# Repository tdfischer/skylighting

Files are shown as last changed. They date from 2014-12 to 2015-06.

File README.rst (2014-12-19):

Noisebridge's skylights are boring and dull.

Lets make them shiny shiny!

The Idea
========

In all of Noisebridge's skylights, a set of RGB LED strips at the base.
Each controlled by a standalone microprocessor connected via ZigBee,
with the network as a whole controlled by a RaspberryPI base station.

The system should be as `Anti-Fragile <Anti-Fragile>`__ as possible:

-  If the power goes out, it should come back on and look neat
-  Each skylight can act independently of hardware failure of any other
   skylight
-  Multiple base station designs can be used to control simultaneously,
   as long as can speak a protocol over ZigBee
-  Wireless by default, wired if available
-  Use of DNS-SD so you don't have to scan the network to find a damn
   basestation
-  Replacing parts is really cheap and easy to do
-  Solar powered, so as to not rely on The Grid
-  Some sort of "Sleep Mode" that is launched after a period of
   inactivity or missing heartbeat

Some really neat uses:

-  Clicking a spot on a map on `Infobanana <Infobanana>`__ turns the
   overhead lighting into a magical directional indicator
-  When someone buzzes the door, perhaps a certain pattern could be
   shown
-  A UI that lets one configure each cell's RGB for an event
-  Automatically turning on/off based on a motion sensor grid in the
   space

The Software
============

-  **`Skyglighting on
   Github <https://github.com/tdfischer/skylighting>`__ - Main issue
   tracker**
-  `Graviton <http://git.phrobo.net/cgit/graviton.git/>`__ -
   Internet+RPI network control, interactivity, and discoverability
-  `Graviton-arduino <http://git.phrobo.net/cgit/graviton-arduino.git/>`__ -
    Port of Graviton to Arduino
-  `gpiotty <https://github.com/phrobo/gpiotty>`__ - RPI+ZigBee
   connectivity

The Hardware
============



   Skylighting\_-\_First\_Blinkings.jpeg
Currently in the prototype stage, but here's what is allocated:

-  Two XBee radios w/ USB serial boards
-  Two RaspberryPIs with wifi dongles
-  Three LED strips
-  Two solar panels
-  One battery

The Plan
========

This is being developed by User:Tdfischer using the following
milestones. Help is welcome and encouraged :)

# Blink some LED lights via Arduino - First prototype
# XBee to XBee communications between two linux systems over USB -
  Establish control environment
# XBee to XBee communications over RaspberryPi GPIO pins - Development
  of gpiotty
# XBee to Arduino communications - Wireless control prototype
# Skylight power supply - Hardware design
# Realtime display update protocol - Development of Graviton/implement
  pixelpusher
# Control interfaces - Providing an API for super neat interactivity

Parts Needed
============

-  Arduino/ZigBee shields
-  Arduinos
-  The full length of LPD8806 LED Strips for all skylights - 45 meters!

   -  `Aliexpress <http://www.aliexpress.com/item/LPD8806-5050smd-dream-color-LED-strip-36LEDs-m-12Pixels-m-no-waterproof-free-shipping/1956523244.html>`__

-  RPI/ZigBee shield
-  Microcontroller selection for skylight units
-  ZigBee chips
-  Battery charger/regulator circuit

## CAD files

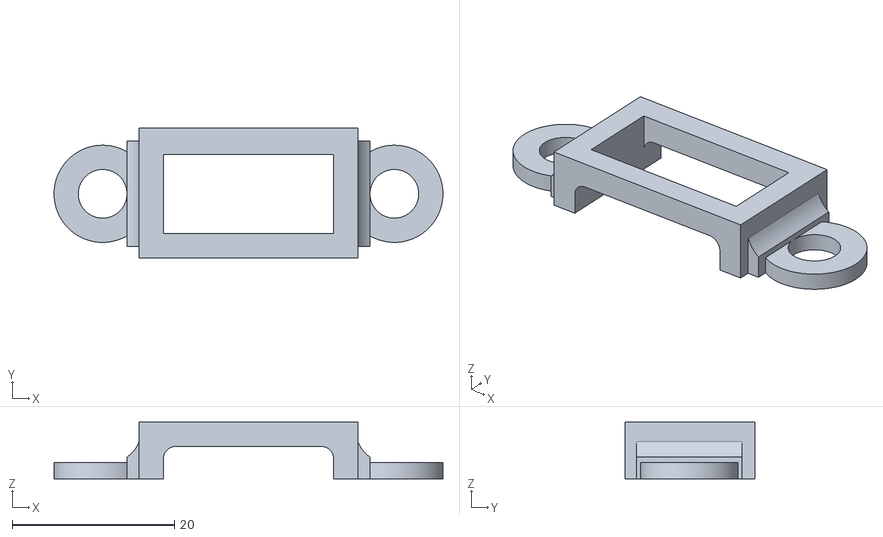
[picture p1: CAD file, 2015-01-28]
openscad/strip-clip.stl
48.0 x 16.0 x 7.01

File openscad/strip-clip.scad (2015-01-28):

// Diameter of the mounting screw
SCREW_DIAMETER = 3; // [0:100]

// Width of your LED strip in millimeters
STRIP_WIDTH = 21; // [0:100]

// Thickness of yoru LED strip in millimeters
STRIP_THICKNESS = 4; // [1:100]

// How wide (along the strip) you want your clip to be in millimeters
CLIP_LENGTH = 13; // [1:100]

// How durable you'd like this to be in millimeters
THICKNESS=3; //[1:100]

// How many screw mounts to have
SCREW_MOUNT_COUNT = 2; //[0, 1, 2]

// Use support bridge?
USE_SUPPORT_BRIDGE = 0; //[0, 1]

difference() {
	translate([-THICKNESS, 0.1, 0.01]) cube(size=[STRIP_WIDTH+THICKNESS*2, CLIP_LENGTH+THICKNESS, STRIP_THICKNESS+THICKNESS]);
	difference() {
		translate([THICKNESS/2, 0, 0]) minkowski() {
			cube(size=[STRIP_WIDTH-THICKNESS, CLIP_LENGTH*2, STRIP_THICKNESS-THICKNESS/2]);
			sphere(r=THICKNESS/2, $fn=80);
		}
		if (USE_SUPPORT_BRIDGE > 0) translate([STRIP_WIDTH/2-THICKNESS/4, -CLIP_LENGTH/2, 0]) cube(size=[THICKNESS/2, CLIP_LENGTH*2, STRIP_THICKNESS+1]);
	}
	translate([0, CLIP_LENGTH/2-(CLIP_LENGTH*0.75-THICKNESS)/2, 0]) cube(size=[STRIP_WIDTH, CLIP_LENGTH*0.75, STRIP_THICKNESS*2]);
}

if (SCREW_MOUNT_COUNT > 0) {
	screwMount();
	if (SCREW_MOUNT_COUNT > 1) translate([STRIP_WIDTH, 0, 0]) mirror([1, 0, 0]) screwMount();
}


module screwMount() {
	translate([-THICKNESS*2.5, CLIP_LENGTH/2+THICKNESS/2, 0]) difference() {
		union() {
			cylinder(r=SCREW_DIAMETER+THICKNESS, h=STRIP_THICKNESS/2, $fn=80);
			difference() {
				translate([THICKNESS, -CLIP_LENGTH/2, 0]) cube(size=[THICKNESS, CLIP_LENGTH, STRIP_THICKNESS+THICKNESS]);
				translate([SCREW_DIAMETER/4, CLIP_LENGTH, THICKNESS*2]) rotate([90, 0, 0]) cylinder(r=STRIP_THICKNESS, h=CLIP_LENGTH*2, $fn=80);
			}
		}
		translate([0, 0, -0.1]) cylinder(r=SCREW_DIAMETER, h=STRIP_THICKNESS, $fn=80);
	}
}

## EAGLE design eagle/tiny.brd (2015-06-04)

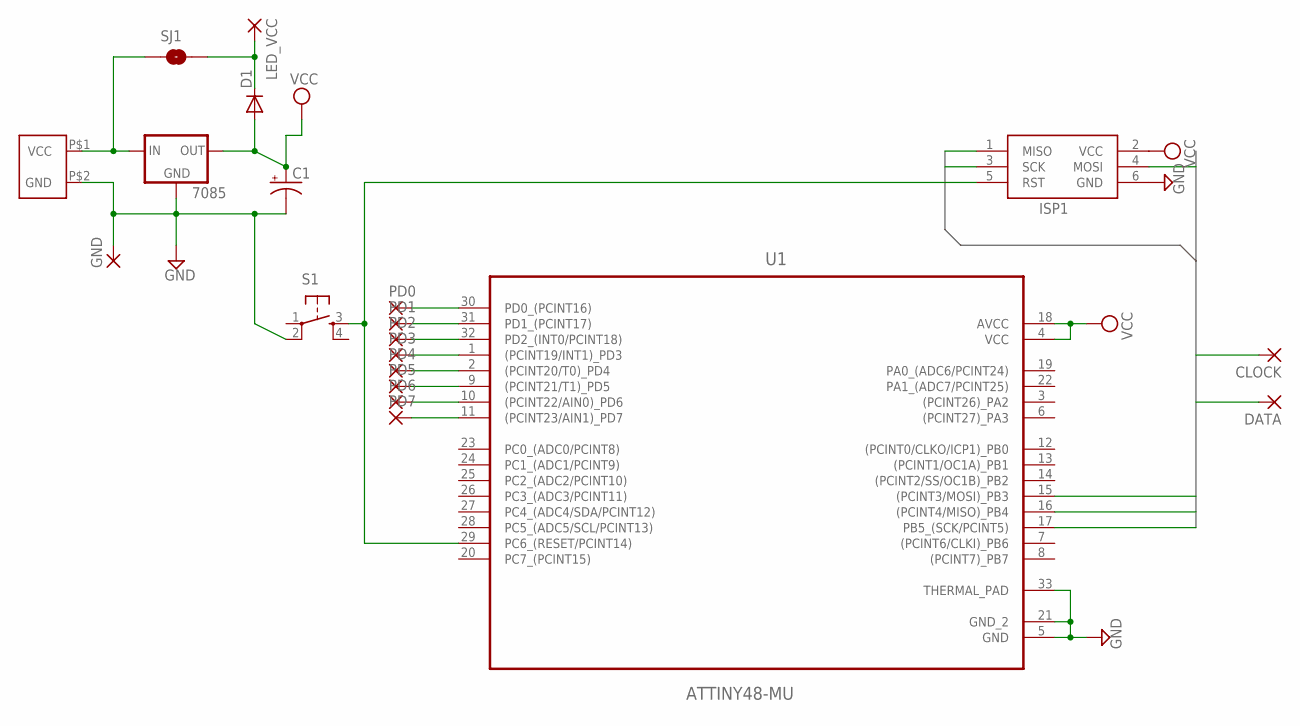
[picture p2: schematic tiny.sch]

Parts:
7085: V_REG_78XXSIDE; 78XXL
C1: CPOL-USE2.5-6; E2,5-6
CLOCK: 2,54/1,0
D1: DIODE1N4148; DIODE-1N4148
DATA: 2,54/1,0
GND: 2,54/1,0
ISP1: AVRISP-6; AVRISP
LED_VCC: 2,54/1,0
PD0, PD1, PD2, PD3, PD4, PD5, PD6, PD7: 1,6/0,9
S1: TAC_SWITCHSMD; TACTILE_SWITCH_SMD
SJ1: LED_VCC = VCC; SJ_2S-NO
U1: ATTINY48-MU; QFN50P500X500X100-33N
VCC: OSTOQ023251

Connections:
GND: 7085.GND, C1.-, GND.1, ISP1.6 (GND), S1.2, U1.5 (GND), U1.21 (GND_2), U1.33 (THERMAL_PAD), VCC.P$2 (GND)
MISO: ISP1.1 (MISO), U1.16 ((PCINT4/MISO)_PB4)
MOSI: DATA.1, ISP1.4 (MOSI), U1.15 ((PCINT3/MOSI)_PB3)
unnamed: ISP1.5 (RST), S1.3, U1.29 (PC6_(RESET/PCINT14))
unnamed: 7085.IN, SJ1.1, VCC.P$1 (VCC)
unnamed: PD0.1, U1.30 (PD0_(PCINT16))
unnamed: PD1.1, U1.31 (PD1_(PCINT17))
unnamed: PD2.1, U1.32 (PD2_(INT0/PCINT18))
unnamed: PD3.1, U1.1 ((PCINT19/INT1)_PD3)
unnamed: PD4.1, U1.2 ((PCINT20/T0)_PD4)
unnamed: PD5.1, U1.9 ((PCINT21/T1)_PD5)
unnamed: PD6.1, U1.10 ((PCINT22/AIN0)_PD6)
unnamed: PD7.1, U1.11 ((PCINT23/AIN1)_PD7)
unnamed: D1.C, LED_VCC.1, SJ1.2
SCK: CLOCK.1, ISP1.3 (SCK), U1.17 (PB5_(SCK/PCINT5))
VCC: 7085.OUT, C1.+, D1.A, ISP1.2 (VCC), U1.4 (VCC), U1.18 (AVCC)

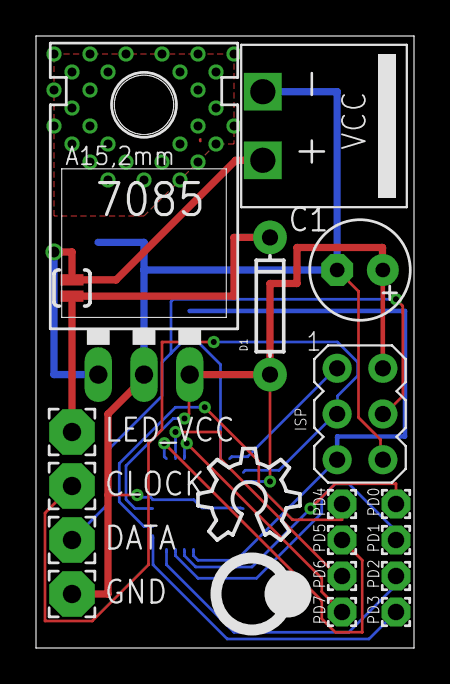
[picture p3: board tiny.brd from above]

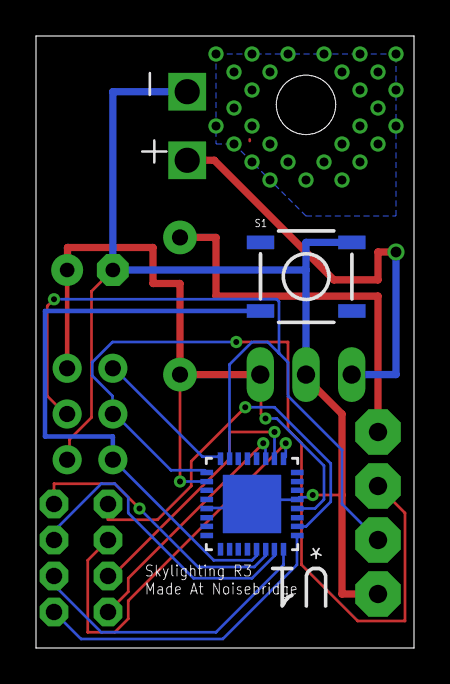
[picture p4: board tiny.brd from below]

Board: 2 copper layers, 21.0 x 34.0 mm, 22 parts (2 on the bottom side), 16 nets.

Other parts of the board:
U$1: PHROBO-LOGO
U$2: OSHW_8X200_NOTEXT

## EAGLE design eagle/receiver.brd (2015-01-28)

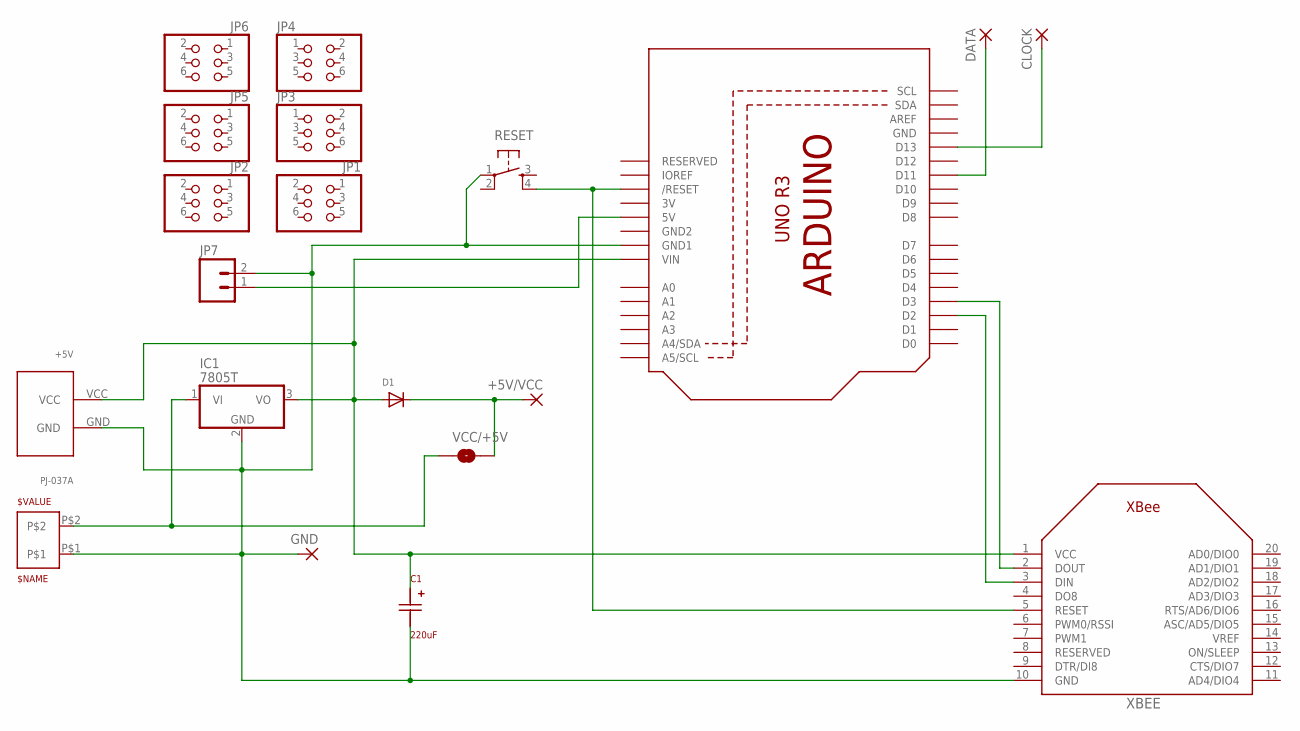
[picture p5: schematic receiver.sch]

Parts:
+5V: PJ-037A
+5V/VCC: 2,15/1,0
C1: 220uF; UWT0J221MCL1GB
CLOCK: 2,15/1,0
D1: DIODESOD-323F; SOD-323F
DATA: 2,15/1,0
GND: 2,15/1,0
IC1: 7805T; TO220H
JP1, JP2, JP3, JP4, JP5, JP6: PINHD-2X3; 2X03
JP7: M02PTH; 1X02
RESET: TAC_SWITCHSMD; TACTILE_SWITCH_SMD
U1: ARDUINOR3-DIMENSION; ARDUINOR3
VCC: OSTOQ023251
VCC/+5V: NC=+5v; SJ_2S-NO
XBEE: XBEE

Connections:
3V: U1.3V
GND: +5V.GND, C1.-, GND.1, IC1.2 (GND), JP7.2, RESET.1, U1.GND, U1.GND1, VCC.P$1, XBEE.10 (GND)
GND2: U1.GND2
unnamed: IC1.1 (VI), VCC.P$2, VCC/+5V.1
unnamed: DATA.1, U1.D11
unnamed: CLOCK.1, U1.D13
unnamed: RESET.4, U1.RESET (/RESET), XBEE.5 (RESET)
unnamed: U1.D2, XBEE.3 (DIN)
unnamed: U1.D3, XBEE.2 (DOUT)
unnamed: JP7.1, U1.5V
unnamed: +5V/VCC.1, D1.C, VCC/+5V.2
VCC: +5V.VCC, C1.+, D1.A, IC1.3 (VO), U1.VIN, XBEE.1 (VCC)

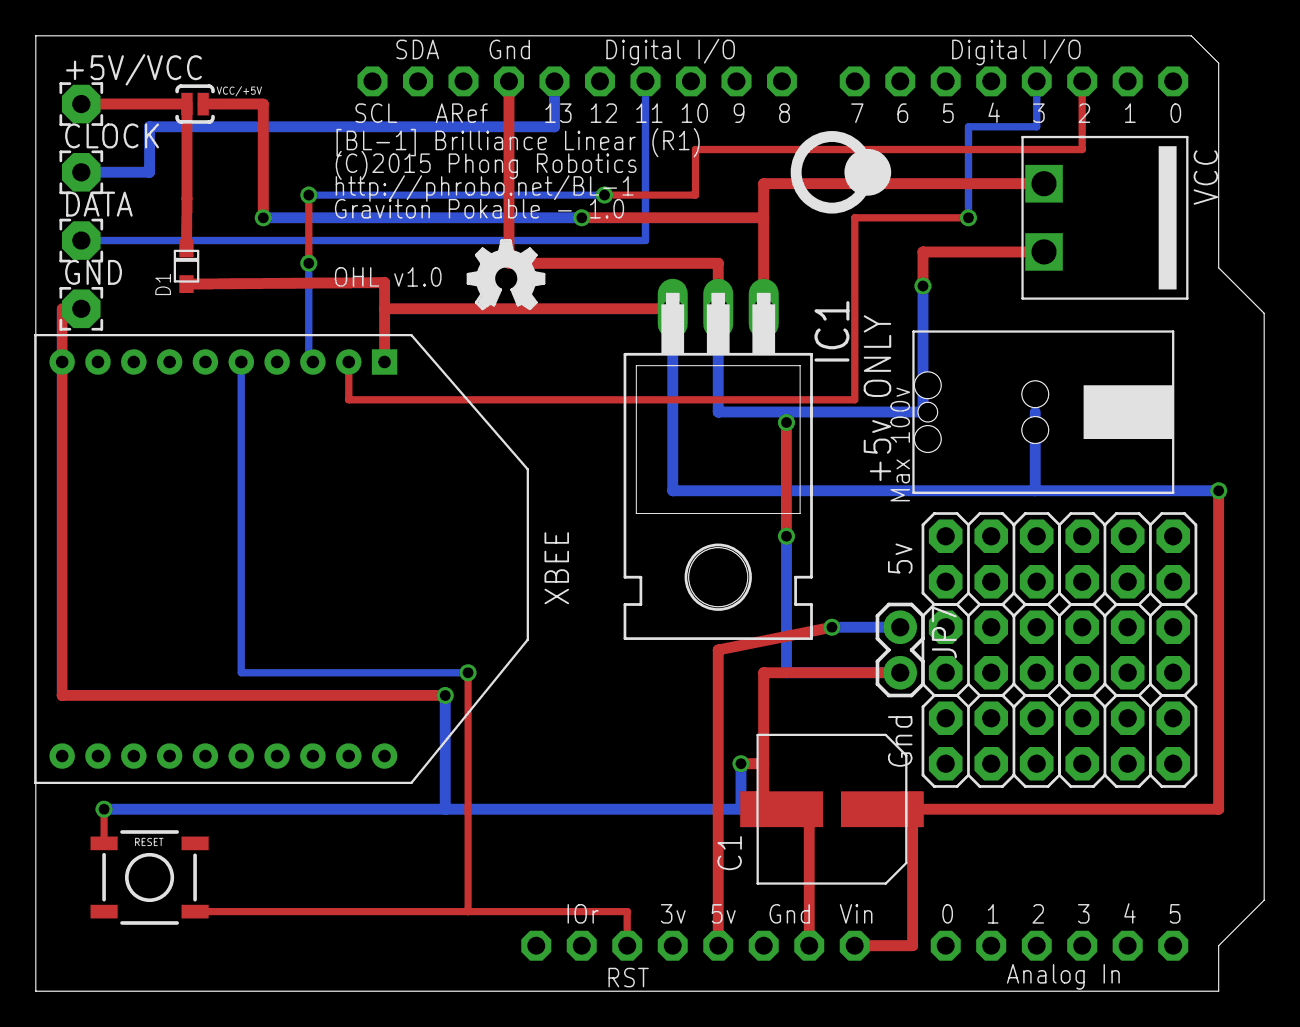
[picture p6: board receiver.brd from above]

Board: 2 copper layers, 68.6 x 53.3 mm, 22 parts (0 on the bottom side), 10 nets.

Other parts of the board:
U$4: PHROBO-LOGO
U$5: OSHW_FILLX150_NOTEXT

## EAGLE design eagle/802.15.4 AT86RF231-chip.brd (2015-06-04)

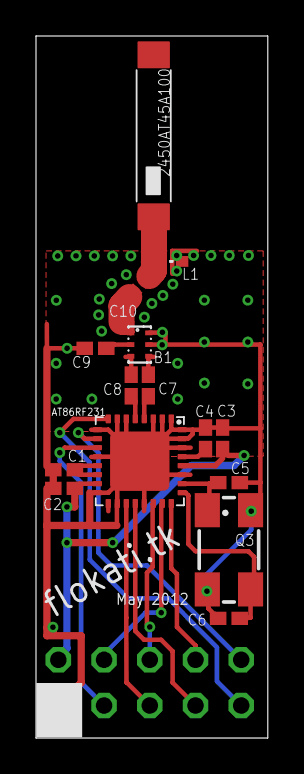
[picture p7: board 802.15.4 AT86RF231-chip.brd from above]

Board: 2 copper layers, 12.9 x 39.0 mm, 16 parts (1 on the bottom side), 21 nets.

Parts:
AT86RF231: AT86RF231; QFN32
B1: 2450FB15L0001; BALUN
C1, C2, C3, C4: 1uF; C0402K
C5, C6: 12pF; C0402K
C7, C8, C9: 22pF RF; C0402K
C10: 1.5pF; C0402K
L1: 3.9nH; 0402
Q3: 16MHz; CTS406
SV1: FE05-2
U$1: 2450AT45A100

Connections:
/RST: AT86RF231.8, SV1.9
/SEL: AT86RF231.23, SV1.4
ANTENNA: C10.2, L1.2, U$1.P$1
AVDD: AT86RF231.29, C4.2
DIG2: AT86RF231.10, SV1.10
DVDD1: AT86RF231.13, AT86RF231.14, C1.2
GND: AT86RF231.1, AT86RF231.2, AT86RF231.3, AT86RF231.6, AT86RF231.7, AT86RF231.9, AT86RF231.12, AT86RF231.16, AT86RF231.18, AT86RF231.21, AT86RF231.27, AT86RF231.30, AT86RF231.31, AT86RF231.32, AT86RF231.EXP, B1.5, C1.1, C2.2, C3.2, C4.1, C5.2, C6.2, C9.2, L1.1, SV1.1
IRQ: AT86RF231.24, SV1.8
MISO: AT86RF231.20, SV1.7
MOSI: AT86RF231.22, SV1.6
unnamed: AT86RF231.26, C5.1, Q3.1
unnamed: AT86RF231.25, C6.1, Q3.3
unnamed: AT86RF231.4, C8.1
unnamed: AT86RF231.5, C7.2
unnamed: B1.3, C7.1
unnamed: B1.4, C8.2
unnamed: B1.2, C9.1
unnamed: B1.1, C10.1
SCLK: AT86RF231.19, SV1.5
SLP_TR: AT86RF231.11, SV1.3
VCC: AT86RF231.15, AT86RF231.28, C2.1, C3.1, SV1.2

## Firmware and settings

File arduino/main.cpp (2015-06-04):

#include <SoftwareSerial.h>
#include <FastLED.h>
#include <XBee.h>
#include <Graviton.h>
#include <graviton-xbee-reader.h>

#include "animation.h"

#ifdef DEBUG
SoftwareSerial dbg_ser (2, 3);
#endif // DEBUG

// Test strip
//#define LED_COUNT 93

// Front glass case at Noisebridge
//#define LED_COUNT 32

// Noisebridge's big Noise^^2 table
//#define LED_COUNT 287

// Lights above the bike rack at Noisebridge
//#define LED_COUNT 120

#define LED_COUNT 28

CRGB leds[LED_COUNT];

static void fadeLEDSegment(uint16_t idx, CRGB goal, int width, int pause=1)
{
  CRGB start = leds[idx];
  for(fract8 i = 0; i < 255; i+=5) {
    CRGB blended = blend(start, goal, ease8InOutCubic(i));
    for (uint16_t segmentIdx = idx; segmentIdx <= idx + width; segmentIdx++) {
      leds[segmentIdx] = blended;
    }
    FastLED.show();
    FastLED.delay(pause);
  }
}

static void fadeLED(uint16_t idx, CRGB goal)
{
  return fadeLEDSegment(idx, goal, 0);
}


class HouselightsAnimation : public Animation {
public:
  HouselightsAnimation() :
    Animation()
  {}

  void redraw()
  {
    for(uint16_t  i = 0; i < LED_COUNT;i++) {
      leds[i] = CHSV (random(230, 255), 10, 255);
    }
    FastLED.show();
    delay(1000);
  }
};

class DirectionAnimation : public Animation {
public:
  DirectionAnimation() :
    Animation()
  {}

  uint8_t hue;

  void redraw()
  {
    uint8_t pos = idx() % LED_COUNT;
    hue = 0;
    for (uint16_t  i = 0; i < LED_COUNT; i++) {
      leds[i] = CHSV(hue, 255, 255 * ((pos - i)/(double)LED_COUNT));
    }
    FastLED.show();
    delay(30);
  }
};

class ThrobAnimation : public Animation {
public:
  ThrobAnimation() :
    Animation()
  {
  }

  void redraw()
  {
    fadeLEDSegment(0, CHSV(245+random(0, 20), random(200, 255), random(200, 255)), LED_COUNT, 60);
  }
};

class TwinkleAnimation : public Animation {
public:
  TwinkleAnimation() :
    Animation(),
    render_func(&TwinkleAnimation::do_fill),
    nextColor(0, 255, 255),
    iterations(0)
  {
    nextColor = CHSV(random(0, 255), 255, 255);
  }

  void (TwinkleAnimation::*render_func)();
  CHSV nextColor;
  uint16_t iterations;

  void redraw()
  {
    (this->*render_func)();
  }

  void do_fill()
  {
    fadeLEDSegment(0, CRGB::White, LED_COUNT);
    fadeLEDSegment(0, CRGB::Black, LED_COUNT);
    render_func = &TwinkleAnimation::do_random_shift;
  }

  void do_random_shift()
  {
    uint16_t pixelIdx = random(0, LED_COUNT);
    fadeLED(pixelIdx, nextColor);
    iterations++;
    if (iterations >= LED_COUNT * 2) {
      //nextColor.h += random(20, 30);
      nextColor.s = max(nextColor.s+random(10, 30), 200);
      iterations = 0;
    }
  }
};

class DropAnimation : public Animation {
public:
  DropAnimation() :
    Animation(),
    pos(LED_COUNT/2),
    width(0),
    max_brightness(255),
    render_func(&DropAnimation::do_starburst)
  {}

  uint16_t pos;
  uint16_t width;
  uint16_t hue;
  uint8_t max_brightness;
  uint8_t brightness;

  /**
   * render_func: Current sub-animation to render
   */
  void (DropAnimation::*render_func)();

  /**
   * redraw: Redraw the current frame
   */
  void redraw()
  {
    (this->*render_func)();
  }

  /**
   * do_starburst: Initial point of light starburst animation thingee
   */
  void do_starburst() {
    for (uint8_t b = 128; b > 0; b-=2) {
      leds[pos] = CHSV(255, 0, b);
      FastLED.show();
      FastLED.delay(5);
    }

    render_func = &DropAnimation::do_expand;
    width = 0;
  }

  /**
   * do_expand: Expansion animation
   */
  void do_expand() {
    width++;
    hue++;
    CHSV curColor = CHSV (hue, 255, max_brightness);

    uint16_t start, end;
    start = max(pos - width, 0);
    end = min(LED_COUNT, pos + width);

    for (uint16_t i = start; i < end; i++) {
      leds[i] = curColor;
    }

    FastLED.show();
    delay(10);

    if (width >= LED_COUNT) {
      render_func = &DropAnimation::do_fadeout;
    }
  }

  /**
   * do_fadeout: Fade out animation
   */
  void do_fadeout() {
    brightness--;
    CHSV curColor = CHSV (hue, 255, min(max_brightness, brightness));
    for (uint16_t i = 0; i < LED_COUNT;i++) {
      leds[i] = curColor;
    }

    FastLED.show();

    if (brightness == 0) {
      render_func = &DropAnimation::do_starburst;
      pos++;
      pos %= LED_COUNT;
    }
    delay (10);
  }
};

DropAnimation idleAnim;
HouselightsAnimation houselightsAnim;
DirectionAnimation directionAnim;
TwinkleAnimation twinkleAnim;
ThrobAnimation throbAnim;
Animation* anim (&throbAnim);

void
do_idle(unsigned char argc, const GravitonMethodArg* argv, GravitonVariant* ret)
{
  anim = &idleAnim;
#ifdef DEBUG
  dbg_ser.println (F ("Idle!"));
#endif // DEBUG
}

void
do_directional(unsigned char argc, const GravitonMethodArg* argv, GravitonVariant* ret)
{
  anim = &directionAnim;
#ifdef DEBUG
  dbg_ser.println (F ("Directional!"));
#endif // DEBUG
}

void
do_houselights(unsigned char argc, const GravitonMethodArg* argv, GravitonVariant* ret)
{
  anim = &houselightsAnim;
#ifdef DEBUG
  dbg_ser.println (F ("House Lights!"));
#endif // DEBUG
}

const GravitonMethod methods[] = {
  { "idle", do_idle },
  { "directional", do_directional },
  { "houselights", do_houselights }
};

const GravitonService services[2] = {
  GravitonService( 
    "net.phrobo.brilliance.linear",
    3,
    methods
  ),
  GravitonIntrospectionService()
};

XBee bee;
GravitonXBeeReader reader (&bee);

GRAVITON_STATIC_INIT (&reader, services, 2);

void setup() {
#ifdef DEBUG
  dbg_ser.begin (9600);
  dbg_ser.println ( F ("Boot"));
#endif // DEBUG

  Serial.begin (9600);
  FastLED.addLeds<LPD8806, GRB>(leds, LED_COUNT);
  //FastLED.addLeds<WS2812, 12, GRB>(leds, LED_COUNT);
  randomSeed (analogRead(0));
  idleAnim.hue = random (255);
  directionAnim.hue = random (255);
  for (uint16_t i = 0; i < LED_COUNT; i++) {
    leds[i] = CHSV (0, 0, 0);
  }
  FastLED.show();
}

void loop()
{
  if (anim->isFinished()) {
    anim->reset();
    anim = &idleAnim;
  }
  Graviton.loop();
  anim->step();
}

void serialEvent() {
  reader.serialEvent ();
}

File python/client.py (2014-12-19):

#!/usr/bin/env python
import serial
import sys
import struct
from xbee import XBee

ser = serial.Serial(sys.argv[1], 9600)

#clear buffer
ser.flushInput()
ser.flushOutput()

xbee = XBee(ser)

TYPE_FIND_SERVICE = 0
TYPE_FIND_METHOD = 1
TYPE_METHOD_CALL = 2

def callMethod_old(service, method, **kwargs):
  pkt = ""
  pkt += struct.pack("!BB", TYPE_METHOD_CALL, len(service))
  pkt += service
  pkt += struct.pack("!B", len(method))
  pkt += method
  pkt += struct.pack("!B", len(kwargs))
  for k,v in kwargs.iteritems():
    pkt += struct.pack("!B", len(k))
    pkt += v
    pkt += struct.pack("!B", len(v))
    pkt += v
  return pkt

_services = {
  'net.phrobo.graviton.introspection': 0
}

_methods= {
  'net.phrobo.graviton.introspection': {
    'ping': 0
  }
}

def readResponse(ser):
  buf = ser.read(1)
  pktType = struct.unpack("<B", buf)[0]
  if pktType == 0:
    print "None!"
    return None
  if pktType == 1:
    print "Int!"
    return struct.unpack("<h", ser.read(2))[0]
  if pktType == 2:
    print "Str!"
    buf = ""
    c = struct.unpack("<B", ser.read(1))[0]
    while c != 0:
      print "Read", c
      buf += chr(c)
      c = struct.unpack("<B", ser.read(1))[0]
    return buf
  print "Unknown type", pktType

def findService(ser, service):
  pkt = ""
  pkt += struct.pack("<BB", 255, TYPE_FIND_SERVICE)
  pkt += service
  pkt += struct.pack("<B", 0)
  ser.write(pkt)
  return readResponse(ser)

def findMethod(ser, serviceIdx, method):
  pkt = ""
  pkt += struct.pack("!BBb", 255, TYPE_FIND_METHOD, serviceIdx)
  pkt += method
  pkt += struct.pack("!B", 0)
  ser.write(pkt)
  return readResponse(ser)

def callMethod(ser, serviceIdx, methodIdx, **kwargs):
  pkt = ""
  pkt += struct.pack("!BBBB", 255, TYPE_METHOD_CALL, serviceIdx, methodIdx)
  #pkt += struct.pack("!B", len(kwargs))
  for k,v in kwargs.iteritems():
    pkt += struct.pack("!B", len(k))
    pkt += v
    pkt += struct.pack("!B", len(v))
    pkt += v
  ser.write(pkt)
  return readResponse(ser)

print 'finding service'
serviceIdx = findService(ser, "net.phrobo.brilliance.linear")
print 'found at', serviceIdx
print 'finding method'
methodIdx = findMethod(ser, serviceIdx, "houselights")
print 'found at', methodIdx
print 'Calling callMethod'
data = callMethod(ser, serviceIdx, methodIdx)
print 'Got result', data

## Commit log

2014-11-10 Add eagle board and LED strip clip
    [receiver.brd, receiver.sch, strip-clip.scad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]
2014-11-15 Add arduino-mk submodule
2014-11-15 Initial commit of arduino code
2014-11-28 Retool animations to have time-independent frames
2014-12-19 Document graviton-arduino dep
2015-01-20 Better power management, improve usability
    - LED strip pins reordered to match most strips
    - Added a reset button
    - Added a diode to protect the arduino from non-5vdc supplies
    - Added a solder jumper to pick between sharing the arduino's 5vdc supply with
    the strip or whatever is on VCC
    - Filter cap on regulator circuit
    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
    [receiver.brd, receiver.sch]
2015-01-28 Parameterize the strip clip and cut a hole in it to reduce LED covering
    [strip-clip.scad, strip-clip.stl]
2015-01-28 Unflip flipped parts
    [receiver.brd, receiver.sch]
2015-01-28 Add some rounded bits and a support bridge for deposition printers
    [strip-clip.scad, strip-clip.stl]
2015-04-04 First draft of the tiny skylighting variant
    [tiny.brd, tiny.sch]
2015-05-17 Fix all the color fading bugs in the twinkle anim
    [main.cpp]
2015-06-04 Make a tiny prototype of skylighting
    [tiny.brd, tiny.sch]
2015-06-04 import an at86rf231 breakout board
    [802.15.4 AT86RF231-chip.brd]

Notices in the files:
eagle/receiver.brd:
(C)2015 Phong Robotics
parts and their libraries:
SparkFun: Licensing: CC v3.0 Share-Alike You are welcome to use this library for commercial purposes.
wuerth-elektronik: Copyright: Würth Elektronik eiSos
